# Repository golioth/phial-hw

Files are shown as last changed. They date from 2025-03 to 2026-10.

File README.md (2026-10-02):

# Phial

A small (~22 mm diameter, round) battery-powered Bluetooth LE sensor board from
Golioth. Rev B.

> **Status:** pre-release cleanup for open-hardware (OSHW) publication.
> Items marked **[UNKNOWN]** below need confirmation before this README is
> final. Everything else was verified against the design files in this repo.

## Hardware summary (Rev B)

| Subsystem | Part / details | Notes |
|---|---|---|
| Main SoC  | Nordic nRF54L15-QFAA | Rev B moved from nRF52 BGA to nRF54L15 DFN |
| PMIC | Nordic nPM2100 (NPM2100-CAAA-R) | not populated on built boards — see Hardware status |
| IMU | ST LIS2DH12 | 3-axis accelerometer, I2C |
| Microphone| ST MP34DT05TR-A | PDM MEMS mic |
| Audio out | Raltron RDTE-4.000-3030-NS1 | electromagnetic transducer (buzzer) |
| BLE antenna | Taoglas WLA.04 | 2.4 GHz chip antenna |
| NFC | Taoglas FXC.24.A flex antenna | nets NFC1/NFC2 |
| Display/UI| 16x 0201 LED ring (Kingbright APG0201SEC-TT) | |
| Buttons | Panasonic EVP-AWED4A + C&K KMS221G | [UNKNOWN] confirm both populated on Rev B |
| Battery | CR2032 coin cell (HF1N holder) | [UNKNOWN] role of 112TR contact / alternate battery options |
| Debug | SWD via Tag-Connect | alignment pins on paste layer |

**[UNKNOWN]** The schematic also references an nRF52840-CKAA-F-R (WLCSP) symbol
and a BME280. It is unclear whether these are an alternate/deprecated variant,
DNP on Rev B, or planned future population. Needs a pass against the Rev B BOM.

## Hardware status (Rev B)

- **The only boards ever built were assembled without the nPM2100.** A
  zero-ohm resistor selects the function and bypasses that section of the
  circuit, so the built variant runs without the Nordic PMIC.
- Consequence: the nPM2100 power path (battery management via VINT/VOUT) is
  designed but **never exercised on hardware** — treat it as unvalidated
  until a PMIC-populated build is made and tested.
- Further validation history not captured in this repo [UNKNOWN].

## Design files

- KiCad 9 project. **Note:** project files are currently named
  `pilulith.*` (the project's former codename). They are being renamed to
  `phial.*` as part of the release cleanup — see the cleanup checklist.
- 6-layer board, 0.8464 mm thick, ENIG finish, JLC06081H (2116/7628) stackup.
- `input/` — local symbol/footprint/3D sources and reference art.
- `pilulith.pretty/` (to be renamed) — project footprints, including Golioth
  and Orleon logo art footprints.

## Manufacturing outputs

**[UNKNOWN / TODO]** Gerbers, drill files, pick-and-place and BOM exports are
not yet committed or attached to a release. The BOM currently lives in
schematic symbol properties (last touched in commit `e64fb58`). A fabrication
package will be attached to a GitHub Release before publication.

## Firmware

Firmware lives in a separate repo: [golioth/phial-fw](https://github.com/golioth/phial-fw)
(currently private).

## License

Hardware in this repository is released under the **CERN Open Hardware
Licence v2 — Permissive (CERN-OHL-P)**. The LICENSE file is being added as
part of the release cleanup. Documentation and artwork are covered by the
same license unless noted otherwise.

Note: `input/art/` contains vendor reference images (Nordic, JLCPCB stackups,
Taoglas antenna drawings) that are **not** covered by this license and may be
replaced with links before publication — see the cleanup checklist.

## Credits

Designed by Chris Gammell at Golioth.

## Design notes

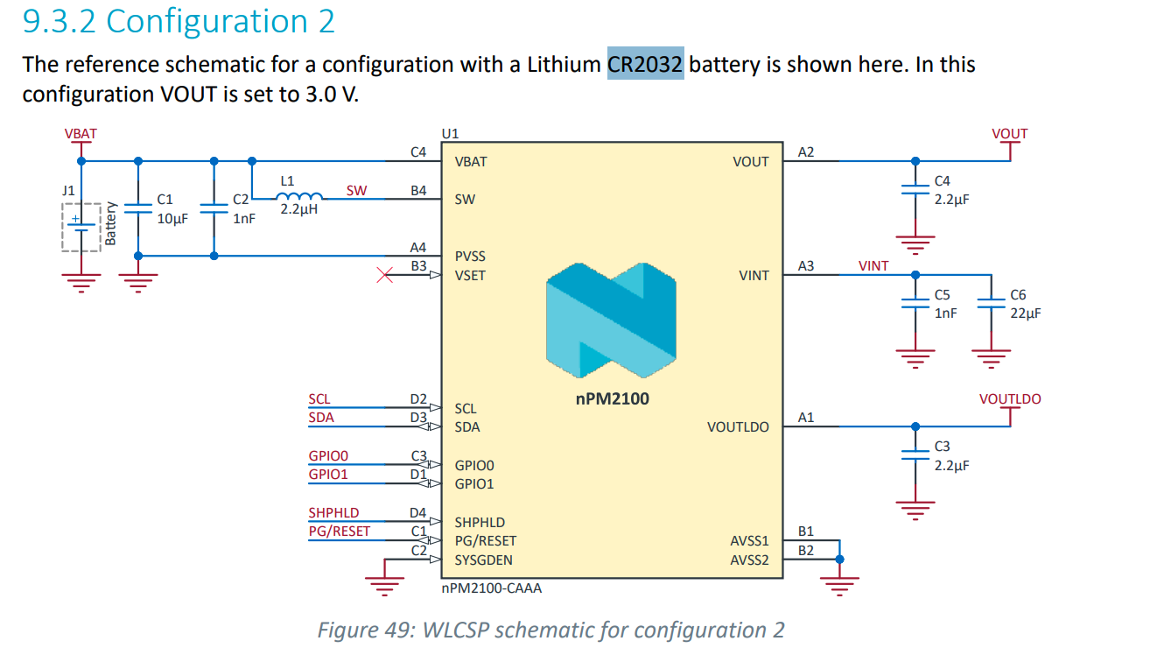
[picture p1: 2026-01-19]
input/art/npm2100-bga-schematic.png

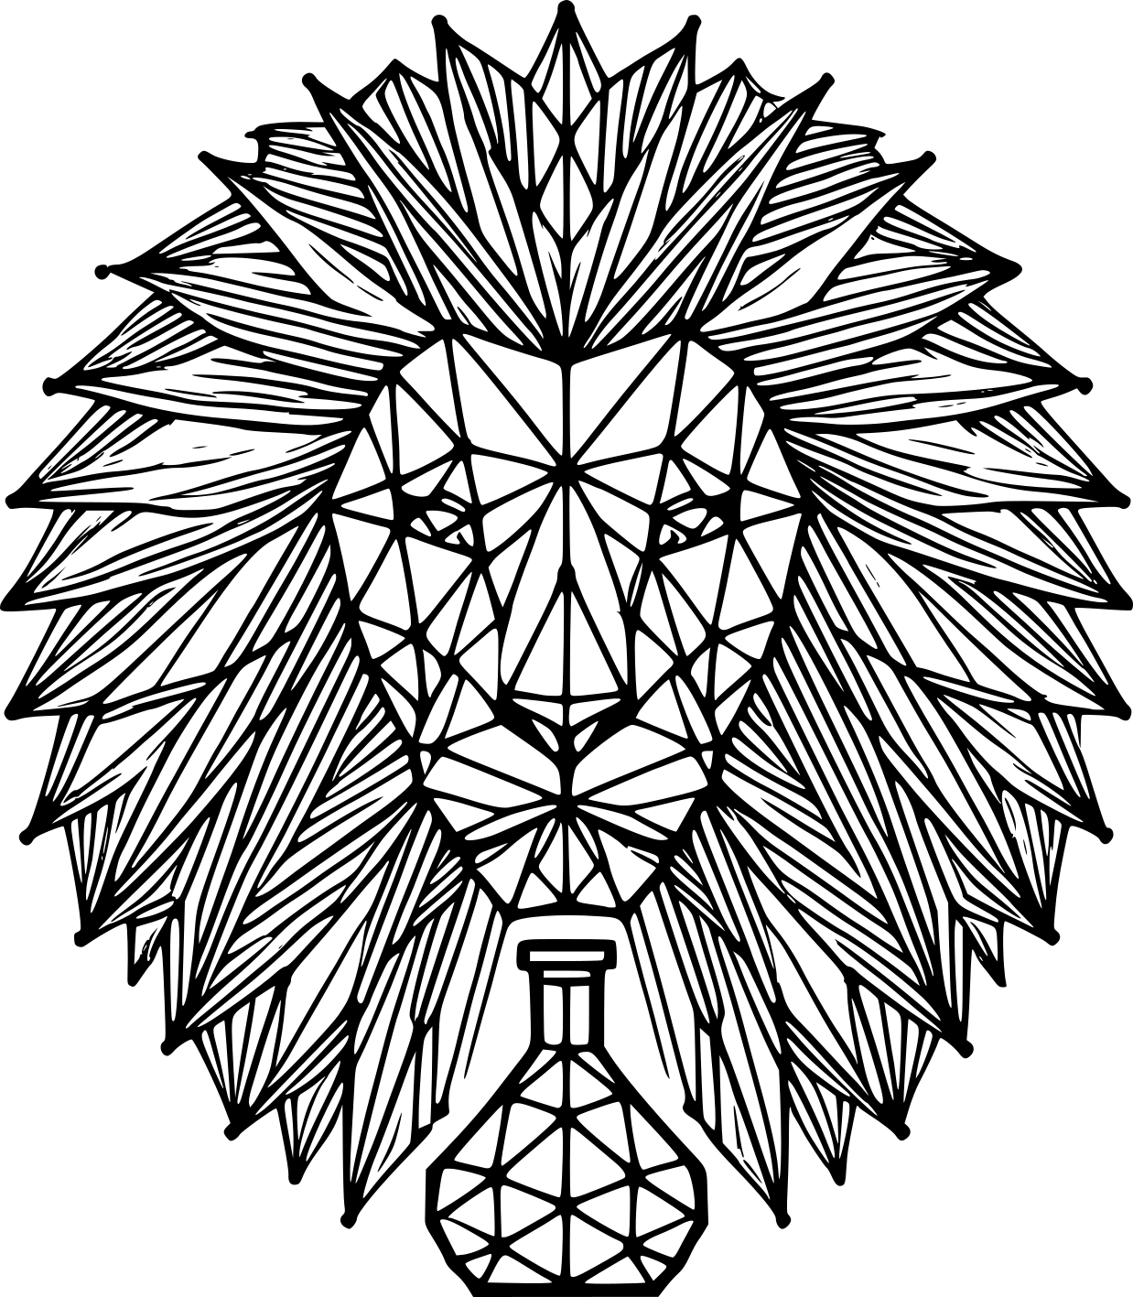
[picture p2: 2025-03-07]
input/art/orleon_36mm.png

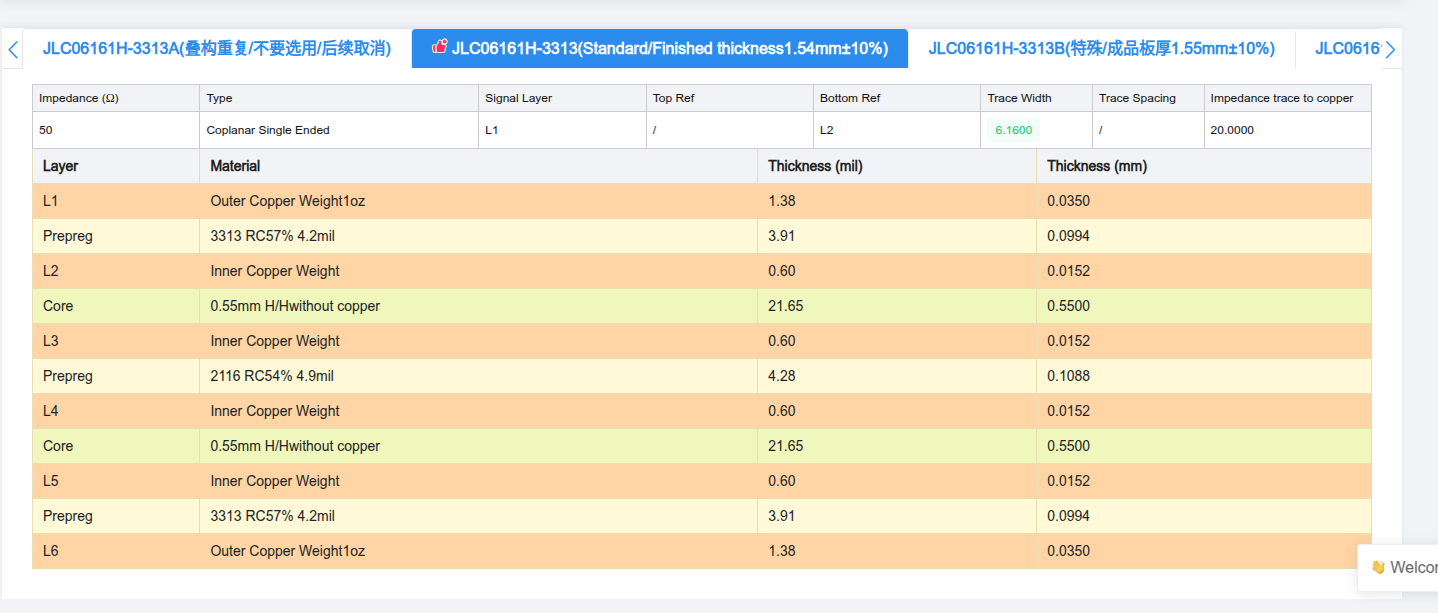
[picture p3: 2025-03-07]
input/art/JLC-0616.png

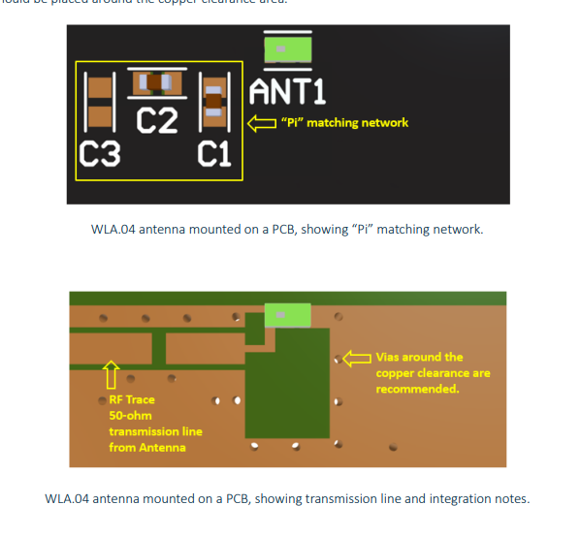
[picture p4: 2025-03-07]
input/art/WLA-04-Layout.png

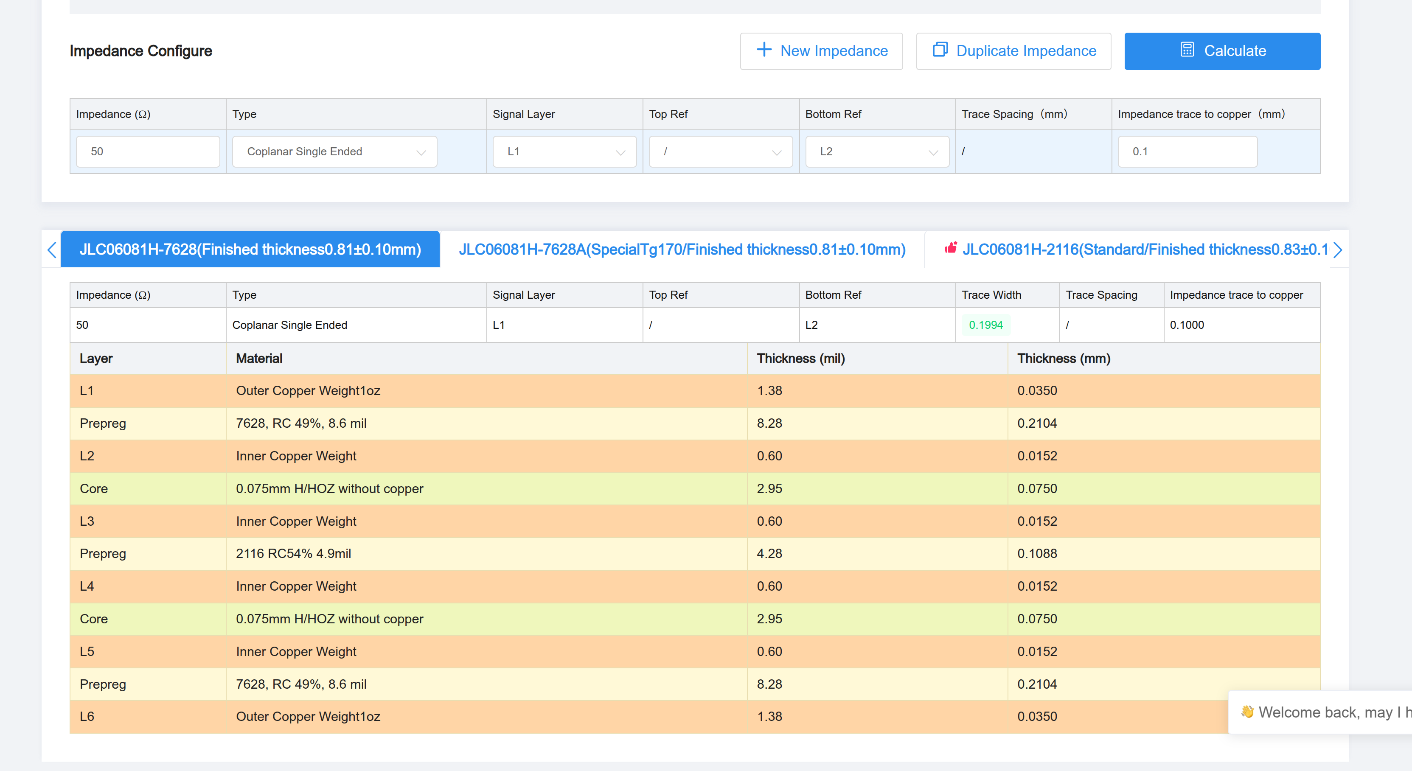
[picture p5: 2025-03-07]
input/art/JLC06081H-7628.png

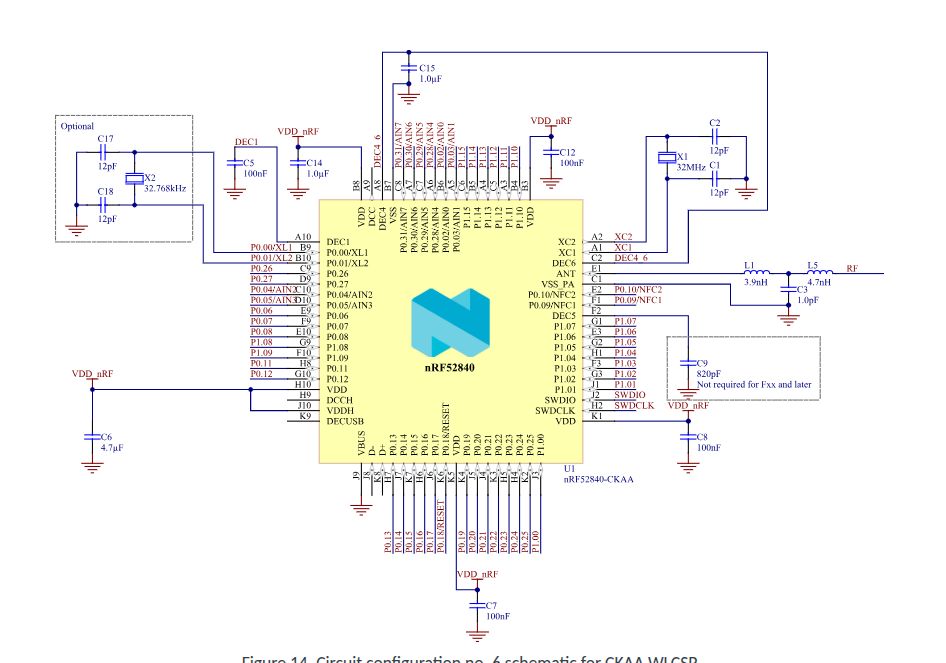
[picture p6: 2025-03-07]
input/art/battery_only_nrf52840_wlcsp.png

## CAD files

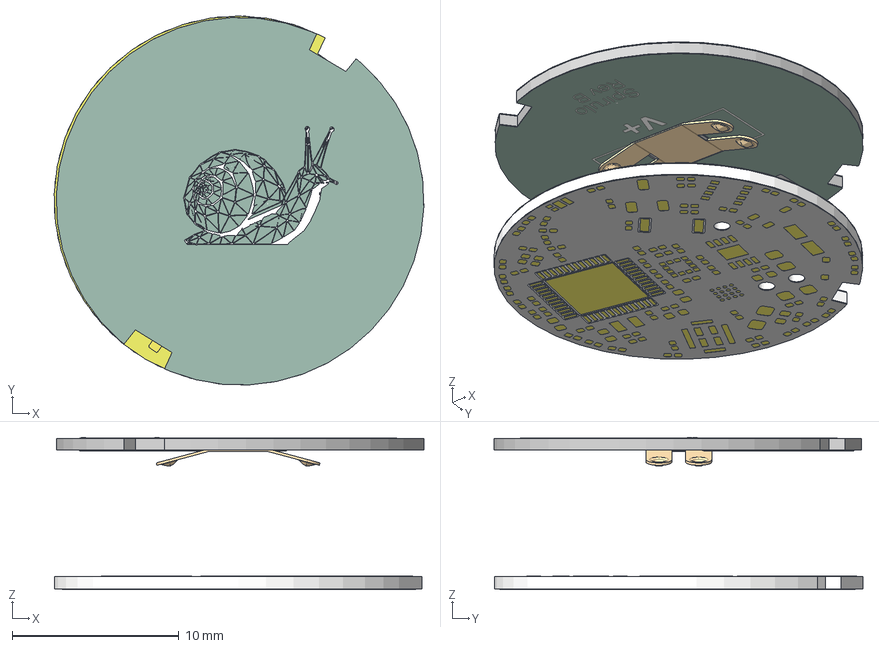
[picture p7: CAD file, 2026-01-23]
input/3d/spirulo-b-202601201646.step
22.2 x 22.2 x 9.18 mm
112TR
pilulith_copper
pilulith_soldermask x 2
pilulith_PCB
spirulo-hw_copper
spirulo-hw_pad
spirulo-hw_via
spirulo-hw_silkscreen x 2
spirulo-hw_soldermask x 2
spirulo-hw_PCB

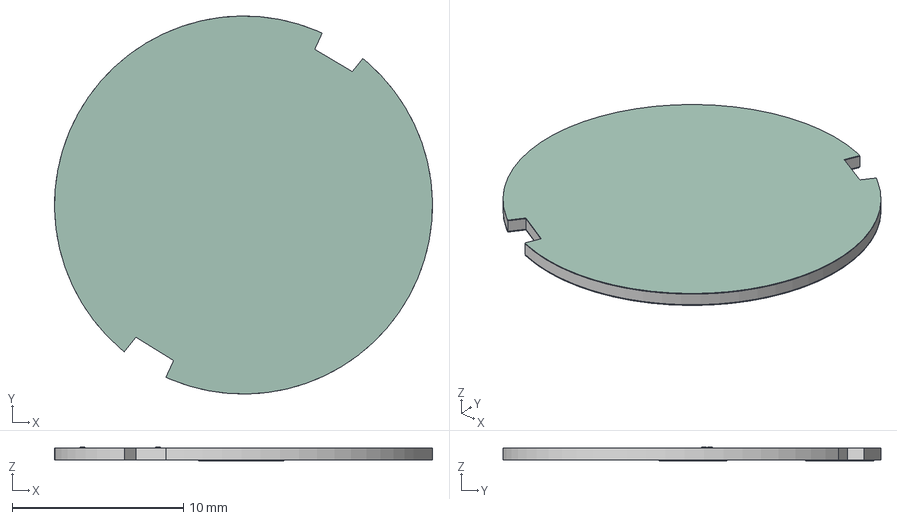
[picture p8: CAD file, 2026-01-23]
input/3d/spirulo-b-202601201631.step
22.1 x 22.1 x 0.81 mm
spirulo-hw_copper
spirulo-hw_soldermask x 2
spirulo-hw_PCB

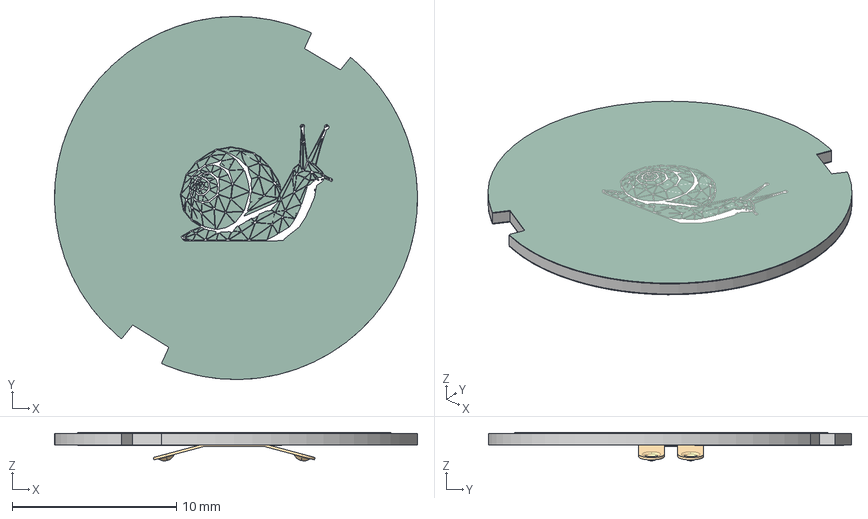
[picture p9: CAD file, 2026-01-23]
input/3d/spirulo-b-202601201651.step
22.1 x 22.1 x 1.76 mm
112TR
spirulo-hw_copper
spirulo-hw_pad
spirulo-hw_via
spirulo-hw_silkscreen x 2
spirulo-hw_soldermask x 2
spirulo-hw_PCB

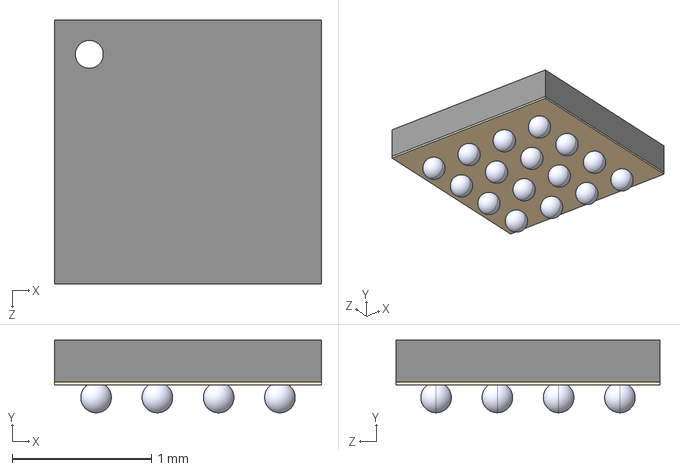
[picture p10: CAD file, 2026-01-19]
input/3d/NPM2100-CAAA-R.step
1.92 x 0.522 x 1.90 mm

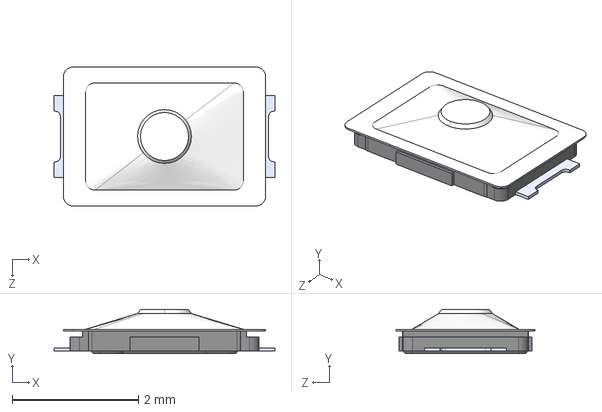
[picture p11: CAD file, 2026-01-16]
input/3d/EVP-AWED4A.step
3.50 x 0.7 x 2.20 mm

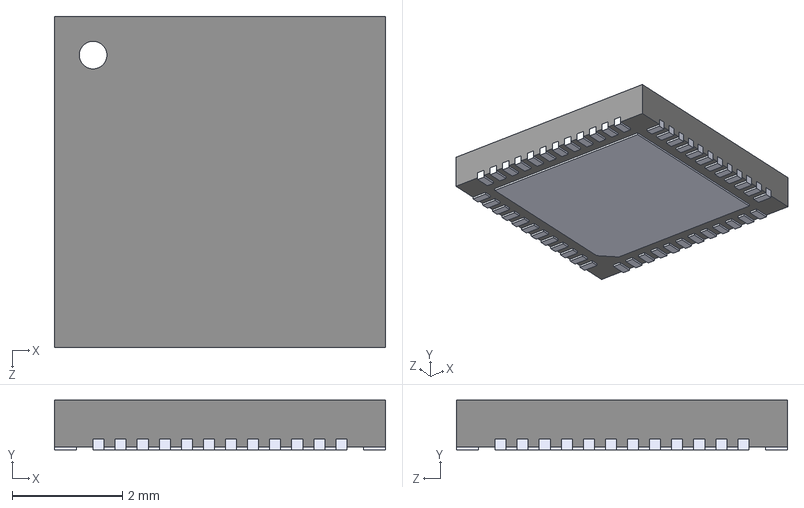
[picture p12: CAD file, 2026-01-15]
input/3d/NRF54L15-QFAA-R.step
6.00 x 0.9 x 6.00 mm

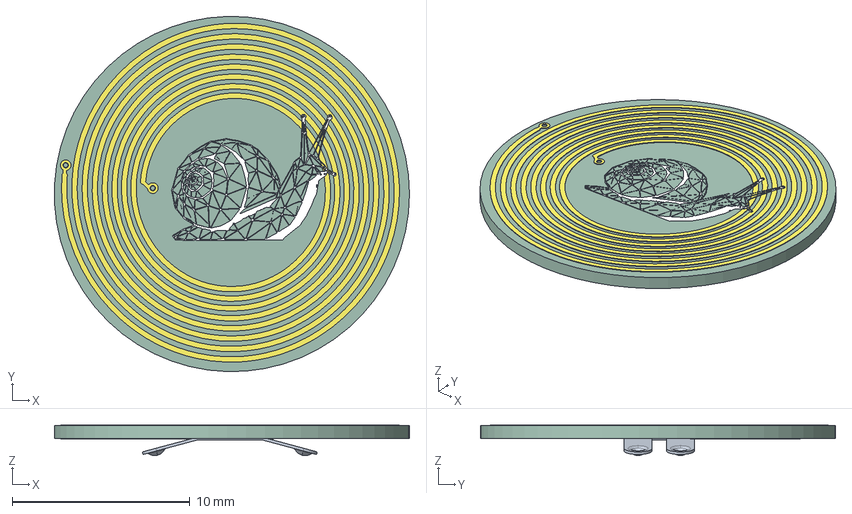
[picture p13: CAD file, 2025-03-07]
input/3d/spirulo_202503071504.step
20.0 x 20.0 x 1.76 mm
112TR
spirulo-hw_copper
spirulo-hw_via
spirulo-hw_silkscreen
spirulo-hw_PCB

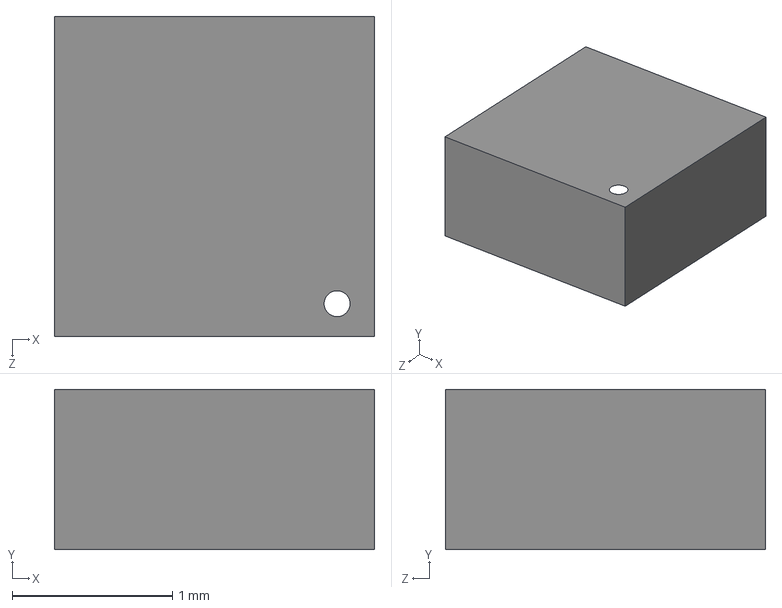
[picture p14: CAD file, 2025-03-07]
input/3d/LIS2DH12.step
2.00 x 1.00 x 2.00 mm

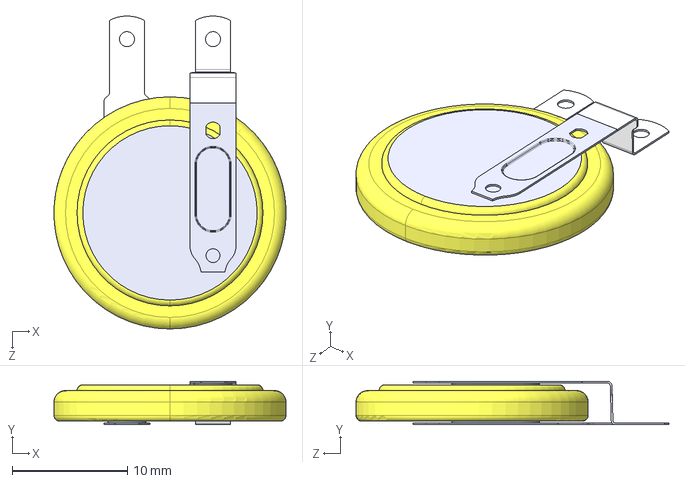
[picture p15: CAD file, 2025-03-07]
input/3d/F1N--3DModel-STEP-56544.STEP
20.1 x 3.75 x 27.1 mm

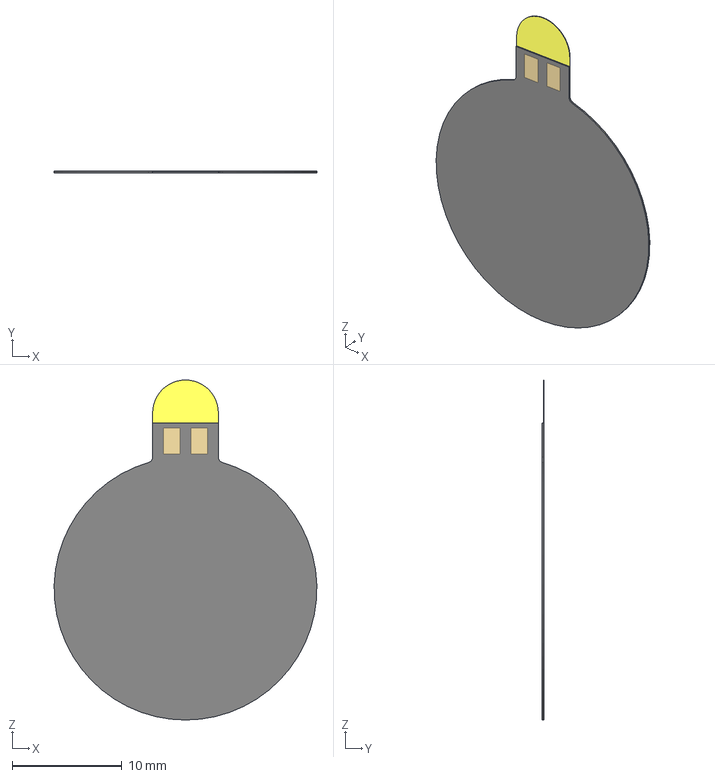
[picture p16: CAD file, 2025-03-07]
input/3d/FXC.24.A.stp
24.0 x 0.16 x 31.0 mm

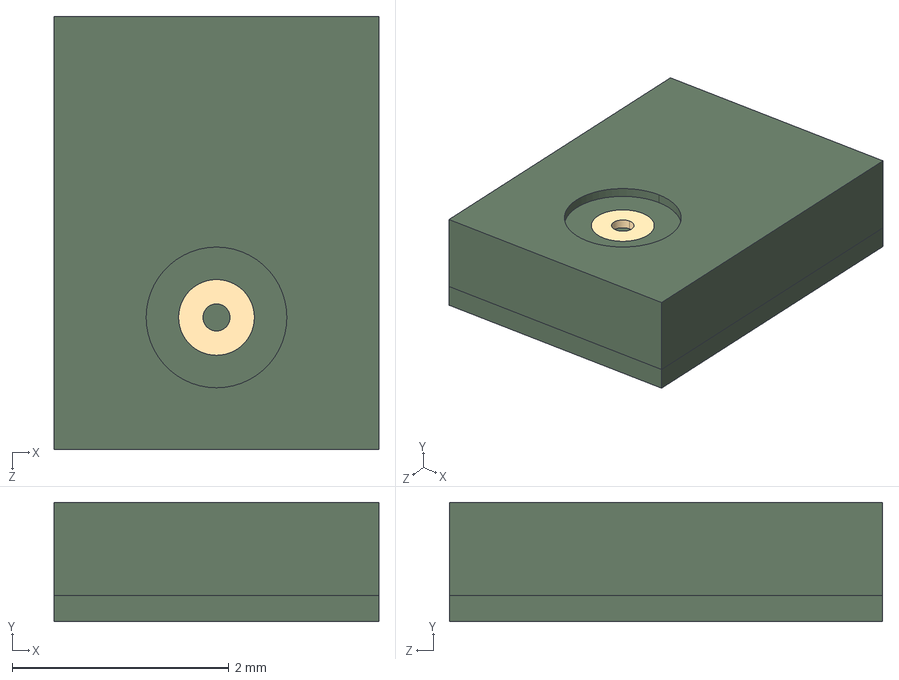
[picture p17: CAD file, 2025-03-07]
input/3d/MP34DT05TR-A.STEP
3.00 x 1.10 x 4.00 mm

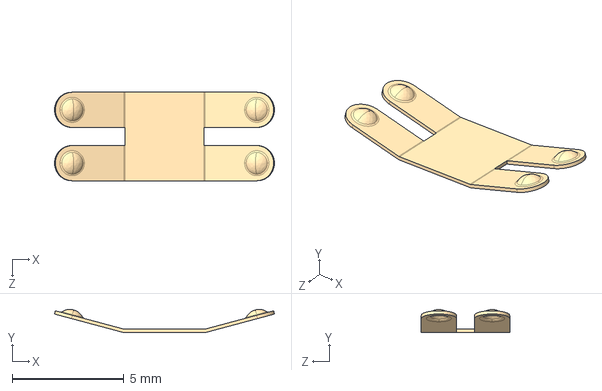
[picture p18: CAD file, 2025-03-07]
input/3d/112TR.step
9.85 x 1.04 x 3.96 mm

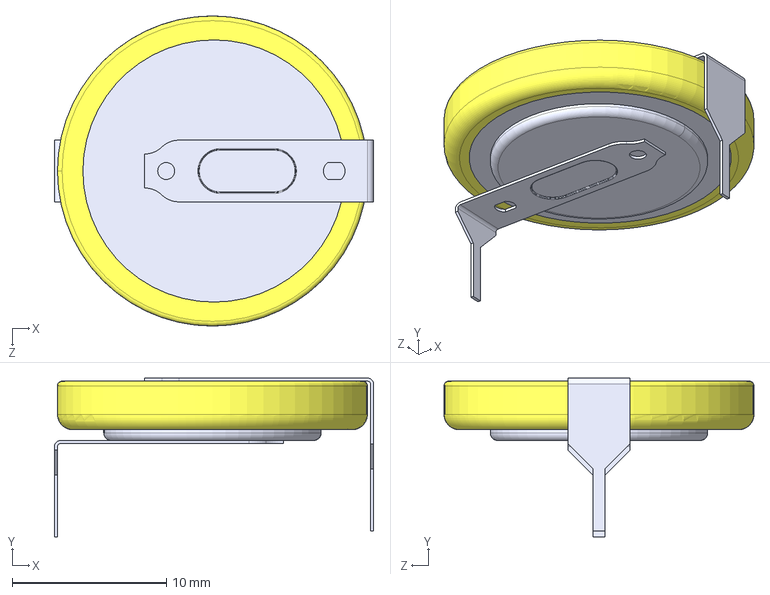
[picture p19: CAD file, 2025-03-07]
input/3d/CR-2032_HF1N.step
20.7 x 10.3 x 20.1 mm

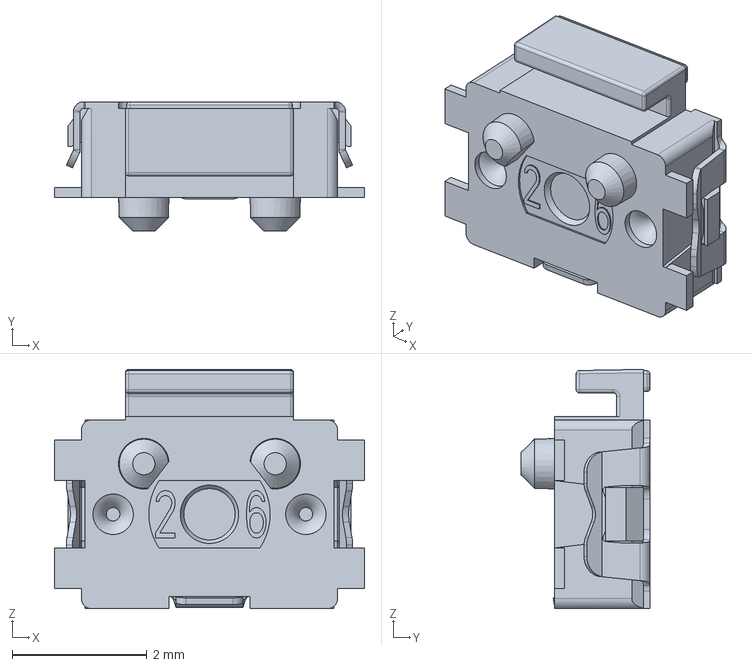
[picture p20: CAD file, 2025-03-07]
input/3d/KMS221GPLFS.stp
4.60 x 1.92 x 3.55 mm

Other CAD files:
input/3d/NRF52840-CKAA-F-R.step

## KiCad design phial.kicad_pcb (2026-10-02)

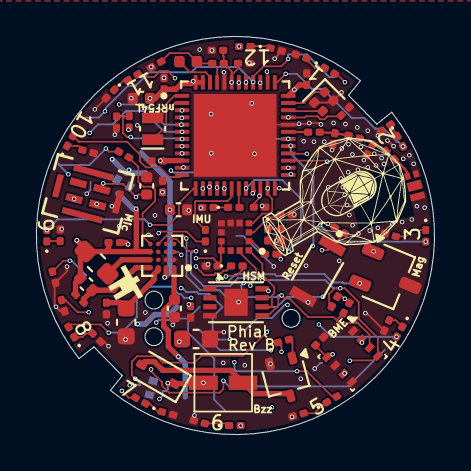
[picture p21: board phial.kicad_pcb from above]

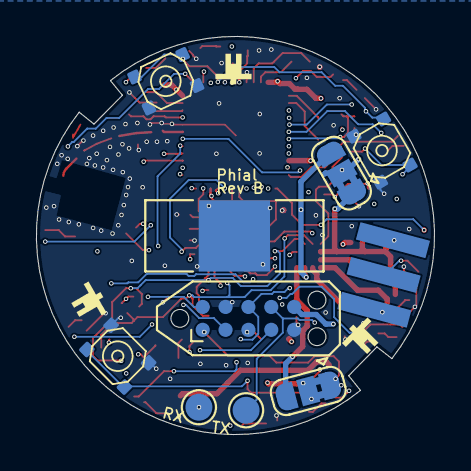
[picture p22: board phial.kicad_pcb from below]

Board: 6 copper layers, 22.1 x 22.1 mm, 95 parts (10 on the bottom side), 75 nets.

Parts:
BT101: 112TR; BAT_112TR
C1, C2: 560P; C_0201_0603Metric
C3, C7: 2U2; C_0201_0603Metric
C4: 10N; C_0201_0603Metric
C5: 2N2; C_0201_0603Metric
C6, C9, C101, C105, C107, C118: 0.1U; C_0201_0603Metric
C8, C117: 1P2; C_0201_0603Metric
C10: 22U; C_0603_1608Metric
C11, C16: 1N; C_0201_0603Metric
C12, C108: 10U; C_0402_1005Metric
C13, C14: 2U2; C_0402_1005Metric
C29: 4U7; C_0603_1608Metric
C104: 1U; C_0402_1005Metric
D3: 1N4148W; D_SOD-323
D101, D102, D103, D104, D105, D106, D107, D108, D109, D110, D111, D112: RED; LED_0201_0603Metric
J101: Conn_01x03_Pin; Cabling
J103: Conn_ARM_JTAG_SWD_10; Tag-Connect_TC2050-IDC-NL_2x05_P1.27mm_Vertical
JP1: npm2100-bridge; SolderJumper-3_P1.3mm_Bridged2Bar12_RoundedPad1.0x1.5mm
JP2: sensor-bridge; SolderJumper-3_P1.3mm_Bridged2Bar12_RoundedPad1.0x1.5mm
L1: FB; L_0201_0603Metric
L2: 2u2; L_0603_1608Metric_Pad1.05x0.95mm_HandSolder
L3: 4U7; L_0402_1005Metric
L4: 2N0; L_0201_0603Metric
L101: 3N9; L_0201_0603Metric
L102: 4N7; L_0201_0603Metric
LED13, LED14, LED15, LED16: RED; LED_0201_0603Metric
LS1: RDTE-4.000-3030-NS1
Q1: SBC847; SOT-323_SC-70
R1, R2, R3, R5, R101, R102, R103, R104, R105, R106, R107, R108, R109, R110, R111, R112: R_Small; R_0201_0603Metric
R4, R6, R8, R66: 0; R_0201_0603Metric
R7: 1K; R_0201_0603Metric
R113, R114, R115: 100K; R_0201_0603Metric
R117, R118: 4K7; R_0201_0603Metric
SW1, SW2, SW3: KMT221NG
SW4: KMT221NG; SW_EVP-AWED4A
TP14, TP15: TestPoint; TestPoint_Pad_D1.5mm
U1: NRF54L15-QFAA-R; QFN40P600X600X90-49N
U2: NPM2100-CAAA-R; BGA16N44P4X4_189X191X52N
U10: LIS2DH; SENSOR_LIS2DH12
U102: WLA.04; SMD4_ANT_WLAp04_TAL
U103: ATECC608B-MAHDA; DFN-8-1EP_3x2mm_P0.5mm_EP1.3x1.5mm
U104: LF21115TMR; TSOT-23
U105: BME280; Bosch_LGA-8_2.5x2.5mm_P0.65mm_ClockwisePinNumbering
U106: MP34DT05TR-A; MP34DT05TR-A_STM
Y101: 32MHz; Crystal_SMD_1210-4Pin_1.2x1.0mm
Y102: 32.768K; Crystal_SMD_MicroCrystal_CM9V-T1A-2Pin_1.6x1.0mm

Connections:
/2.07/T0: LED16.2 (A), U1.18 (P2.07/TRACEDATA(0)/SWO)
/2.08/T1: LED13.2 (A), U1.19 (P2.08/TRACEDATA(1))
/2.09/T2: LED14.2 (A), U1.20 (P2.09/TRACEDATA(2))
/2.10/T3: LED15.2 (A), U1.21 (P2.10/TRACEDATA(3))
/ANT_FEED: L4.2, U102.1 (RF_FEED)
/ANT_NRF: L101.1, U1.31 (ANT)
/ANT_PI: C117.2, L101.2, L102.1
/BATTERY_MEAS: R113.1, R114.2, U1.7 (P1.06/ASO(1)/AIN2)
/BOOT: R8.1, SW1.1, SW2.1, SW3.1, U1.40 (P1.12/ASI(3)/RADIO(3)/AIN5)
/BUZZER: R7.1, U1.29 (P0.04/GRTCLFCLKOUT)
/CR2032_V+: C11.1, C12.1, J101.3, JP1.1 (A), L2.1, R6.1, U2.C4 (VBAT)
/IMU_INT: U1.39 (P1.11/ASO(3)/RADIO(2)/AIN4), U10.12 (INT1)
/LED01: D101.2 (A), U1.38 (P1.10/ASI(2)/RADIO(1))
/LED02: D102.2 (A), U1.37 (P1.09/ASO(2)/RADIO(0))
/LED03: D103.2 (A), U1.28 (P0.03/GRTCPWM)
/LED04: D104.2 (A), U1.27 (P0.02)
/LED05: D105.2 (A), U1.17 (P2.06/TRACECLK)
/LED06: D106.2 (A), U1.16 (P2.05)
/LED07: D107.2 (A), U1.15 (P2.04)
/LED08: D108.2 (A), U1.14 (P2.03)
/LED09: D109.2 (A), U1.13 (P2.02)
/LED10: D110.2 (A), U1.12 (P2.01)
/LED11: D111.2 (A), U1.11 (P2.00)
/LED12: D112.2 (A), U1.42 (P1.14/RADIO(5)/AIN7)
/MAG: U1.41 (P1.13/RADIO(4)/AIN6), U104.2 (OUT)
/MIC_CLK: U1.6 (P1.05/ASI(0)/RADIO(6)/AIN1), U106.3 (CLK)
/MIC_DATA: U1.5 (P1.04/ASO(0)/AIN0), U106.4 (DOUT)
/NFC1: C1.1, J101.1, U1.3 (P1.02/NFC1)
/NFC2: C2.2, J101.2, U1.4 (P1.03/NFC2)
/Power_Insert: J103.6 (SWO/TDO), R6.2
/RESET_N: R66.1, SW4.1, U1.30 (~RESET), U2.C1 (PG/RESET)
/SCL: R117.2, U1.24 (P0.01), U2.D2 (SCL), U10.1 (SCL/SPC), U103.6 (SCL), U105.4 (SCK)
/SDA: R118.2, U1.23 (P0.00), U2.D3 (SDA), U10.4 (SDA/SDI/SDO), U103.5 (SDA), U105.3 (SDI)
/SW: L2.2, U2.B4 (SW)
/SWCLK: J103.4 (SWCLK/TCK), U1.26 (SWDCLK)
/SWDIO: J103.2 (SWDIO/TMS), U1.25 (SWDIO)
/VINT-NPM2100: C10.1, C16.1, U2.A3 (VINT)
/VOUT-NPM2100: C14.1, JP1.3 (B), U2.A2 (VOUT)
/VOUTLDO-NPM2100: C13.1, JP2.3 (B), U2.A1 (LSOUT/VOUTLDO)
/nRF52_RX: J103.8 (NC/TDI/RX), TP15.1, U1.8 (P1.07/ASI(1)/AIN3)
/nRF52_TX: J103.7 (TX), TP14.1, U1.9 (P1.08/CLK16M/EXTREF)
DCC: L3.2, U1.46 (DCC)
DECA: C3.1, C4.1, C5.1, L1.1, U1.33 (DECRF), U1.43 (DECA)
DECD: C7.1, L1.2, L3.1, U1.45 (DECD)
GND: BT101.N, C1.2, C2.1, C3.2, C4.2, C5.2, C6.2, C7.2, C8.1, C9.2, C10.2, C13.2, C14.2, C16.2, C29.2, C101.2, C104.2, C105.2, C107.2, C108.2, C117.1, C118.2, J103.3 (GND), J103.5 (GND), J103.9 (GNDDetect), Q1.2 (E), R1.2, R2.2, R3.2, R4.1, R5.2, R101.2, R102.2, R103.2, R104.2, R105.2, R106.2, R107.2, R108.2, R109.2, R110.2, R111.2, R112.2, R114.1, SW1.2, SW2.2, SW3.2, SW4.2, U1.32 (VSS_PA), U1.44 (VSS), U1.49 (VSS), U2.B1 (AVSS1), U2.B2 (AVSS2), U10.5 (RES_5), U10.6 (GND), U10.7 (GND), U10.8 (GND), U102.3 (GND), U102.4 (GND), U103.4 (GND), U103.9 (EP), U104.3 (GND), U105.1 (GND), U105.5 (SDO), U105.7 (GND), U106.5 (GND), Y101.2, Y101.4
unnamed: C8.2, L4.1, L102.2
unnamed: D3.2 (A), LS1.2, Q1.3 (C)
unnamed: D101.1 (K), R101.1
unnamed: D102.1 (K), R102.1
unnamed: D103.1 (K), R103.1
unnamed: D104.1 (K), R104.1
unnamed: D105.1 (K), R105.1
unnamed: D106.1 (K), R106.1
unnamed: D107.1 (K), R107.1
unnamed: D108.1 (K), R108.1
unnamed: D109.1 (K), R109.1
unnamed: D110.1 (K), R110.1
unnamed: D111.1 (K), R111.1
unnamed: D112.1 (K), R112.1
unnamed: J103.10 (~RESET), R66.2
unnamed: LED13.1 (K), R1.1
unnamed: LED14.1 (K), R5.1
unnamed: LED15.1 (K), R2.1
unnamed: LED16.1 (K), R3.1
unnamed: Q1.1 (B), R7.2
unnamed: U1.1 (P1.00/XL1), Y102.2
unnamed: U1.2 (P1.01/XL2), Y102.1
unnamed: U1.34 (XC1), Y101.3
unnamed: U1.35 (XC2), Y101.1
unnamed: C11.2, C12.2, U2.A4 (PVSS)
unnamed: R8.2, U2.D4 (SHPHLD)
unnamed: R115.1, U10.2 (CS)
unnamed: R4.2, U10.3 (SDO/SA0)
VCC: C6.1, C9.1, C101.1, C107.1, C108.1, J103.1 (VTref), JP1.2 (C), JP2.1 (A), R113.2, U1.10 (VDD), U1.22 (VDD), U1.36 (VDD), U1.47 (VDD), U1.48 (VDD)
VSENSOR: C29.1, C104.1, C105.1, C118.1, D3.1 (K), JP2.2 (C), LS1.1, R115.2, R117.1, R118.1, U10.9 (VDD), U10.10 (VDD_IO), U103.8 (VCC), U104.1 (VCC), U105.2 (CSB), U105.6 (VDDIO), U105.8 (VDD), U106.1 (VDD)

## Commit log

2025-03-07 DRC passes
    [pilulith.kicad_pcb]
2025-03-07 Removing additional warnings
    [pilulith.kicad_pcb]
2025-03-07 added logo and changed for cheaper process. Found out it's a 22 mm board, whoops
    [pilulith.kicad_pcb]
2025-03-07 Rotated battery connector to match the spirulo board cabling
    [pilulith.kicad_pcb, spirulo_202503071504.step]
2026-01-15 Modified to use nRF54L15 and DFN instead of BGA nRF52. Moving parts to match
    [NRF54L15-QFAA-R.step, pilulith.kicad_sch]
2026-01-16 initial routing complete
    [EVP-AWED4A.step, pilulith.kicad_pcb, pilulith.kicad_sch]
2026-01-19 putting in a no popped npm2100 for future proofing
    [NPM2100-CAAA-R.step, pilulith.kicad_pcb, pilulith.kicad_sch]
2026-01-20 rev b first pass done with no violatio ns
    [pilulith.kicad_pcb, pilulith.kicad_sch]
2026-01-20 added second notch and moved associated components
    [pilulith.kicad_pcb]
2026-01-23 add updated spirulo design into 3d space
    [pilulith.kicad_pcb, spirulo-b-202601201631.step, spirulo-b-202601201646.step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]
2026-01-23 fix missing connections on npm2100
    [pilulith.kicad_pcb, pilulith.kicad_sch]
2026-01-23 add tag connect alignment pins to paste layer
    [pilulith.kicad_pcb]
2026-02-19 add part info to BOM
    [pilulith.kicad_pcb, pilulith.kicad_sch]
2026-10-02 OSHW release prep: docs, license, project rename (pilulith -> phial)
    [phial.kicad_pcb, phial.kicad_sch]
2026-10-02 README: add Rev B hardware status — built variant bypasses nPM2100 (unvalidated PMIC path)
